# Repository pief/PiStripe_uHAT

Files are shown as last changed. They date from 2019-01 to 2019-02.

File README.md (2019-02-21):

# PiStripe uHAT

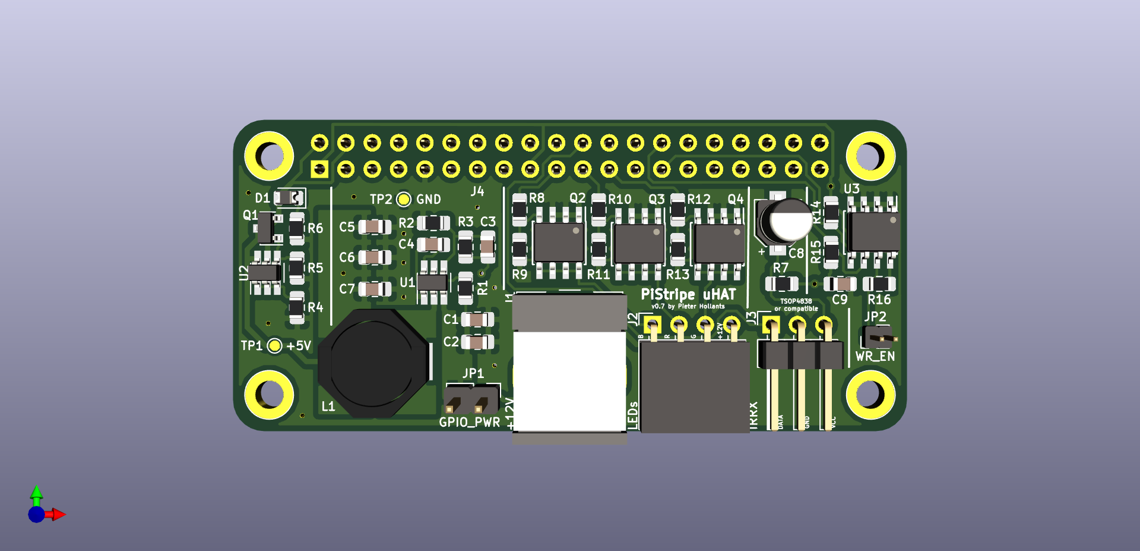
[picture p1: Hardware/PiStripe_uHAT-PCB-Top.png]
Image of PCB top side


## Background

Surely I'm not the only one having both a Raspberry Pi and an LED stripe flying around. In my case it was a "dumb", analogue 12V RGB LED stripe, meaning an LED strip without individually addressable LEDs - instead you generate different colors on the entire LED stripe by using pulse width modulation (PWM) on the R, G and B lines.

Interestingly, while there are plenty of tutorials on connecting such an LED stripe to the Raspberry Pi using transistors I wasn't able to find a ready-to-use HAT doing this. There are plenty of HATs driving LEDs directly mounted on the HAT (e.g. [Pimoroni's Ubercorn](https://shop.pimoroni.com/products/ubercorn) and [Unicorn](https://shop.pimoroni.com/products/unicorn-hat) HATs) and
there is [ManiacalLabs' PiPixel HAT](https://www.tindie.com/products/ManiacalLabs/pipixel-raspberry-pi-led-strip-hat/) but that one drives "digital" WS2812-based LED strips, not dumb ones such as mine. Knight of Pi simply [soldered the transistors on Adafruit's ProtoHAT](http://www.knight-of-pi.org/color-mixer-control-a-rgb-led-strip-with-the-raspberry-pi-and-the-n-channel-mosfet-irlb8721/)
but that seemed to me a bit too hackish for permanent use.

The closest existing solution is the [ANAVI Light pHAT](https://www.crowdsupply.com/anavi-technology/light-phat). It is designed for 12V RGB LED strips such as mine, however there were some points I didn't like. For instance, it uses a quite big screw terminal
where I'd prefer a more compact pin header that matches the existing LED strip connector. But most of all, I don't like having to use two power supplies, one with 12V for the LED strip and still one with 5V for the Raspberry Pi. Unfortunately, with the ANAVI pHAT, it was decided to not implement the back powering option, i.e. integrating a switching regulator to convert 12V to 5V and supply these to the Raspberry Pi via the GPIO pins. Instead the PCB space was used for various options for all kinds of sensors,
something I don't really need.

So I thought, inspite of being not literate at electronics enough I'd build something myself and take the best parts and features of existing solutions and combine them into a HAT of my own. After all, that's what open hardware is all about!

And with great success: the PiStripe uHAT has now been built and tested successfully!

## Features

The PiStripe uHAT is a board of the size of the Raspberry Pi Zero, thus a uHAT (not a HAT) as defined by the Raspberry Foundation. It can be attached on any Raspberry Pi with the 40 pin connector, not just the Pi Zero (W).

The uHAT features the following five functions:

- a 12V -> 5V buck converter based on Texas Instruments' [TPS54202](http://www.ti.com/lit/ds/symlink/tps54202.pdf) chip to implement "back powering" the Raspberry Pi via the GPIO pins, doing away with the need to use two power supplies (one 12V for the LED strip, one 5V for the Raspberry Pi).
- a "perfect" reverse current blocking diode schematic as described in the
  [Raspberry Foundation Add-On board / HAT design guide](https://github.com/raspberrypi/hats/blob/master/designguide.md) to prevent damage when accidentally connecting both 5V to the RPi via its MicroUSB connector and supplying power via my HAT does
  not cause damage.
- the actual LED strip driving
- the possibility to connect an external IR receiver such as a TSOP 34838 so you can use [LIRC](http://lirc.org/) to decode the signals sent by the LED strip's original remote control. External because the HAT is mounted on the Raspberry Pi which in turn will probably be hidden away in some corner whereas you will want to place the IR receiver at a place where it can actually "see" the remote control.
- an ID EEPROM so the board qualifies officially as a HAT as described in the [Raspberry Foundation Add-On board / HAT design guide](https://github.com/raspberrypi/hats/blob/master/designguide.md).

## Hardware

The PiStripe uHAT is not a ready-to-buy product. In fact it's not even a product as such. Instead, it's a do-it-yourself project. Consult the **Hardware** directory for the KiCad project files, including a parts list and the PCB ready for etching.

## Software

The PiStripe uHAT's ID EEPROM needs to be programmed once with the binary in the **Software/EEPROM** directory. The **Software** directory additionally contains some examples on how to use the PiStripe uHAT.

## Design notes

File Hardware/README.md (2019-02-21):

# PiStripe uHAT

## Hardware

The current v0.7 revision of the PiStripe uHAT has been successfully built and tested with the following remarks nonwithstanding:
- the pullups R9, R11 and R13 are probably unnecessary if the ID EEPROM is changed to use the Raspberry Pi's internal pull-up resistors.
- I used a bit of a too small font size, so if you can't read everything, it's not your eyes...

### GPIOs used

The PiStripe uHAT uses the following GPIO pins:

| GPIO pins | Pin name | Usage | Exclusive |
| :---: | :---: | :---: | :---: |
| 1, 17 | +3.3V | IR receiver, ID EEPROM | No |
| 2, 4 | +5V | Back powering Raspberry Pi | No |
| 6, 9, 14, 20, 25, 30, 34, 39 | GND | Ground | No |
| 19 | GPIO10_SPI_MOSI | LED color 1 (e.g. Red) | Yes |
| 21 | GPIO09_SPI_MISO |  LED color 2 (e.g. Green)  | Yes |
| 22 | GPIO25 | IR receiver data | Yes |
| 23 | GPIO11_SPI_CLK  | LED color 3 (e.g. Blue)  | Yes |
| 27 | ID_SD | ID EEPROM I2C Data | No |
| 28 | ID_SC | ID EEPROM I2C Clock | No |

### Jumpers

There are two jumpers:

| Jumper | Name | Function |
| :----: | :---: | :---: |
|  JP1 | GPIO_PWR | Open: Raspberry Pi is powered over Micro USB connector |
| | GPIO_PWR | Closed: Enable back powering the Raspberry Pi via GPIO |
|  JP2 | WR_EN  | Open: Normal usage |
| | WR_EN  | Closed: ID EEPROM can be programmed |

Whether you leave JP1 open or closed depends on whether you want to use the "back powering" feature, thus requiring only the LED stripe's +12V power supply, or keep supplying the Raspberry Pi via its Micro USB connector. Even if you accidentally close JP1 and still connect power to the Pi's Micro USB connector, nothing should go wrong thanks to the "perfect" reverse current blocking diode.

JP2 should only be closed once to program the ID EEPROM (no instructions and software for this yet) and stay open afterwards to prevent accidental flashing.

### Design files

The board's schematic and PCB have been designed with [KiCad](http://www.kicad-pcb.org), a really powerful Open Source EDA solution and a worthy alternative to commercial products such as Eagle.

#### Schematic

Here's an image of the schematic:

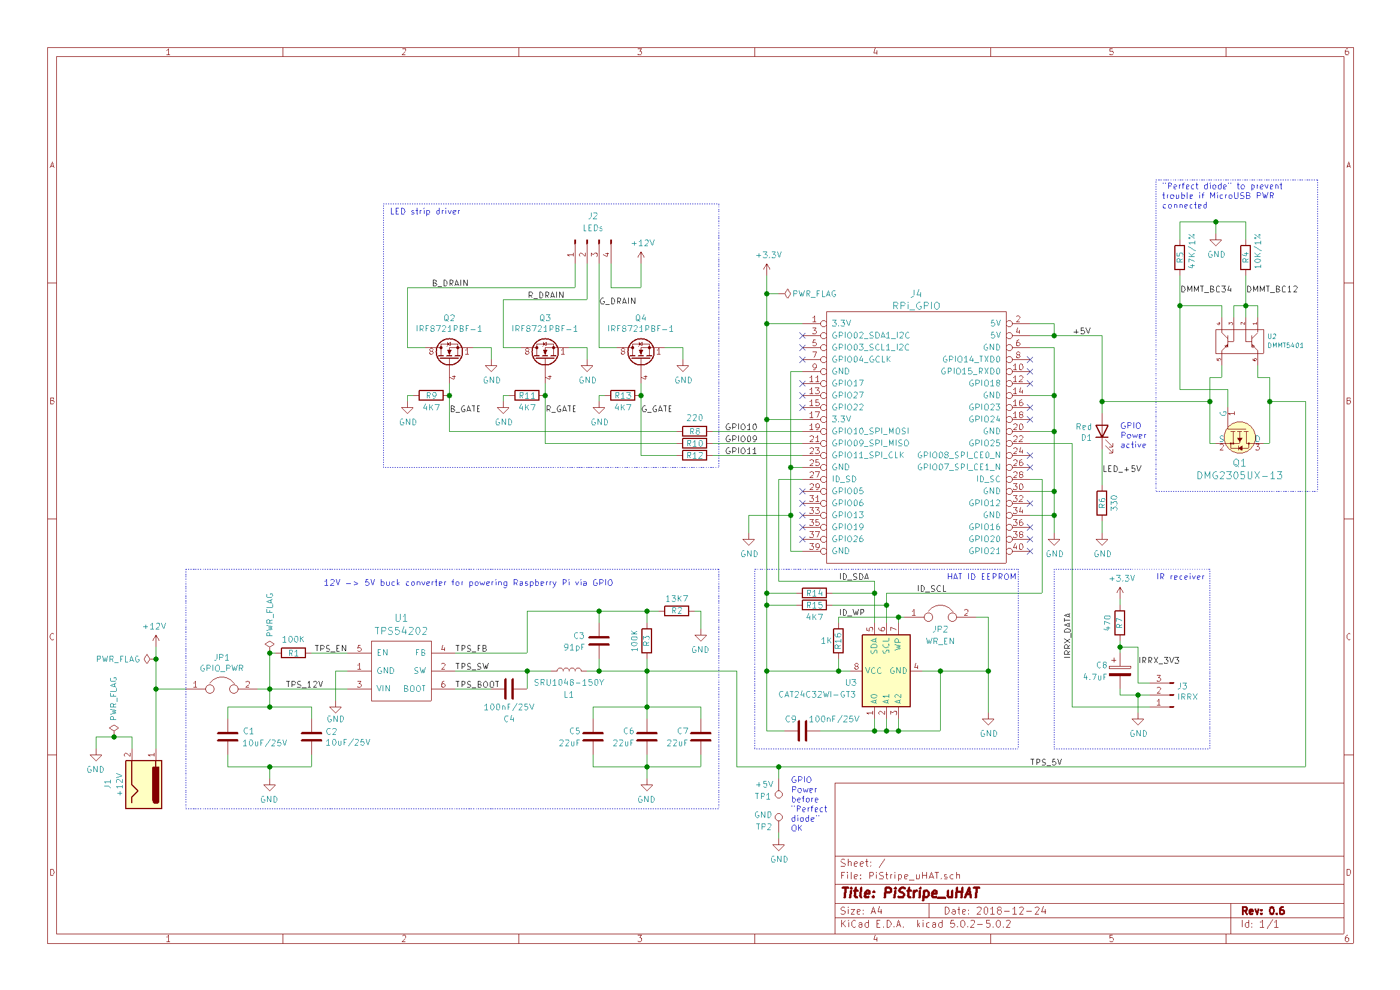
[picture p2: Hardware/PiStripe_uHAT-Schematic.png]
Image of Schematic


As you can see, the schematic is clearly divided into different blocks that corrospond to the functions listed above, so comparisons with the original sources for the schematics (see [Credits](#credits)) should be rather easy.

#### PCB

Here are some images of the PCB:

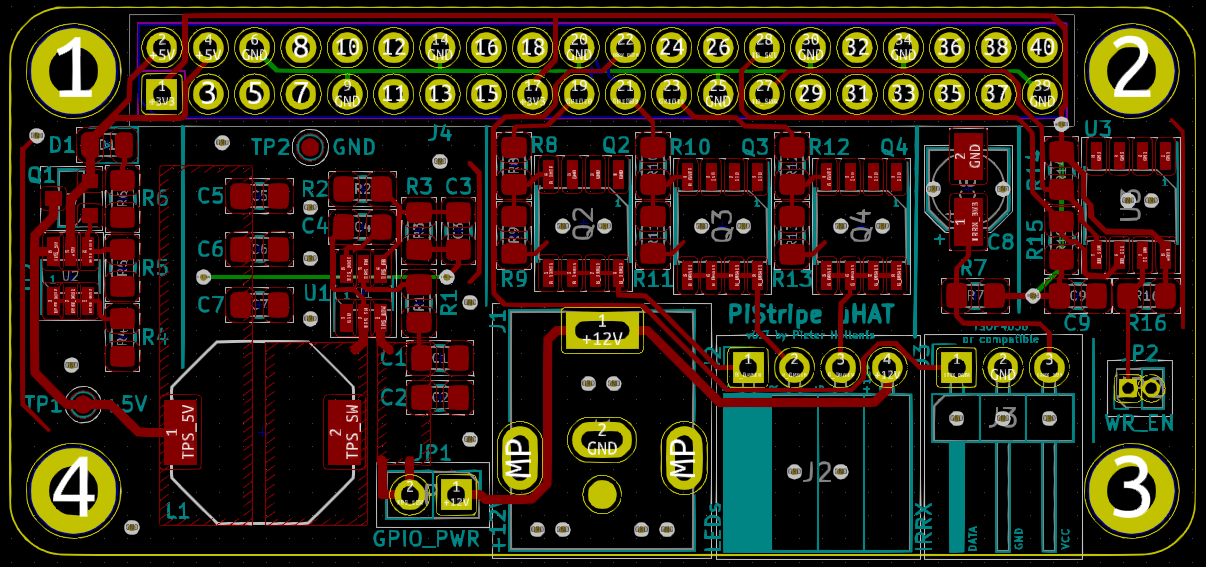
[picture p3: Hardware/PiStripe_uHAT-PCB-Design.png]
Image of naked PCB design

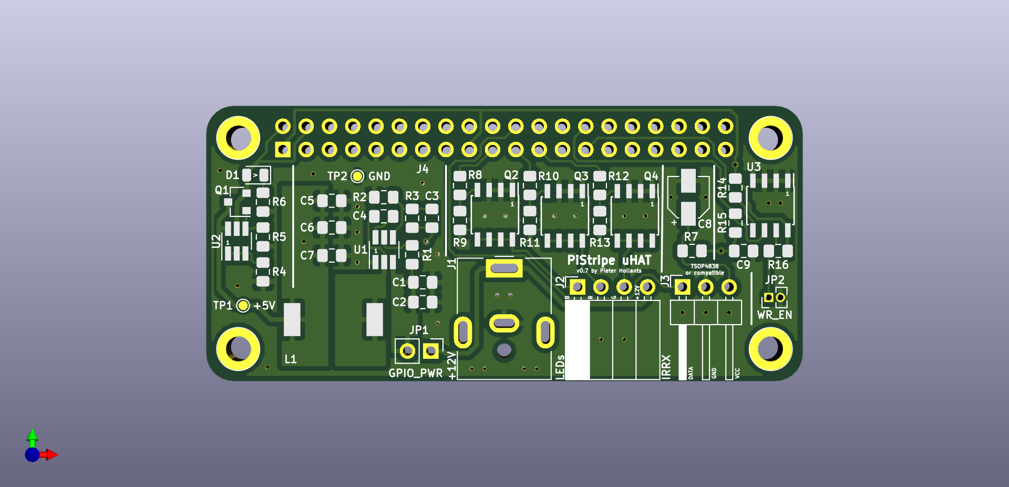
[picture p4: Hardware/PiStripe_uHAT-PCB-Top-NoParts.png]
Image of PCB top side without parts

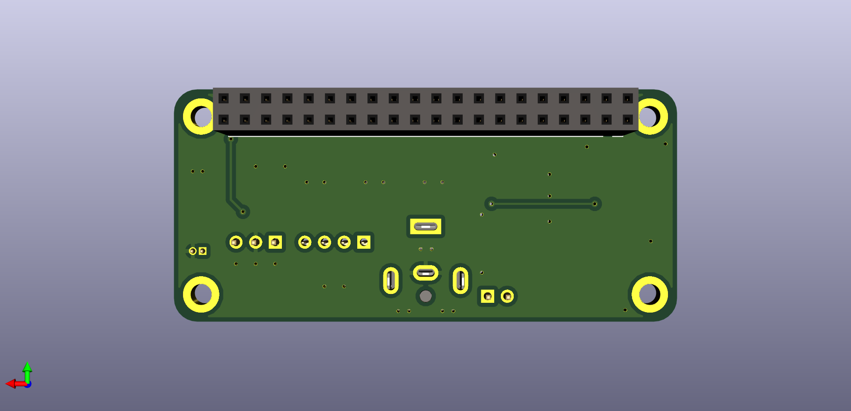
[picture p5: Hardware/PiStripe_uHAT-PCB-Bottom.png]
Image of PCB bottom side

Image of PCB top side

Like the schematic, the PCB has guiding lines printed on top to isolate the different function blocks.

#### Parts list

Please consult the [CSV part list](Hardware/PiStripe_uHAT_Parts.csv) for details.

### Credits

I'm not really inventing something new here but merely combining existing stuff into something new, so I'm standing on the shoulders of giants and try to give appropriate credits here. A big "Thank you" to the following people:

- **Alain Pannetrat** posted the Texas Instruments' [TPS54202](http://www.ti.com/lit/ds/symlink/tps54202.pdf)-based schematic and PCB for [Adding a DC power jack to the Raspberry Pi](https://www.omzlo.com/articles/adding-a-dc-power-jack-to-the-raspberry-pi-v2) on his omzlo.com blog. He did not explicitly specify a license, so I'll assume CC-BY-SA.
- **The Raspberry Foundation** published the circuit for the "perfect" reverse current blocking diode in their [Add-On board / HAT design guide](https://github.com/raspberrypi/hats/blob/master/designguide.md) (see the section "Back Powering the Pi via the GPIO Header" there and the [ZVD circuit schematic](https://github.com/raspberrypi/hats/blob/master/zvd-circuit.png).
- **Leon Anavi** published the schematic and PCB for his [ANAVI Light pHAT](https://www.crowdsupply.com/anavi-technology/light-phat) and his [ANAVI Infrared pHAT](https://www.crowdsupply.com/anavi-technology/infrared-phat) under the [CC-BY-SA 4.0](https://creativecommons.org/licenses/by-sa/4.0/) license. The LED driving circuit, the IR receiver circuit and the basic PCB design such as board dimensions, mounting holes etc. are based on his work. Note that for the IR receiver I use pin 22 (GPI25) instead of pin 12 (GPIO18) to be compatible with the [pHAT DAC](https://de.pinout.xyz/pinout/phat_dac).
- **Mike Lawrence** posted a [RPi_Zero_pHat_Template](https://github.com/mikelawrence/RPi_Zero_pHat_Template) from which I used symbols in ``Connector-ML.lib`` for the schematic. The template is licensed under the [MIT license](https://github.com/mikelawrence/RPi_Zero_pHat_Template/blob/master/LICENSE).
- **Digikey** provides a [KiCAD library](https://github.com/digikey/digikey-kicad-library) from which I used symbols in ``dk_Transistors-FETs-MOSFETs-Single.lib`` for the schematic. The library is licensed under the [CC-BY-SA 4.0](https://github.com/digikey/digikey-kicad-library/blob/master/LICENSE.md) license.
- **L. Bernstone** posted the schematic and design for a [3V3 DC/DC power supply layout using TPS54202](https://github.com/lbernstone/TPS54202/) from which I used symbols in ``tps54202.lib`` for the schematic.
- **Tinkerforge** provides [KiCAD libraries](https://github.com/Tinkerforge/kicad-libraries) from which I used symbols in ``DMMT5401.lib`` for the schematic. They are licensed under the [CERN Open Hardware License v1.1](https://github.com/Tinkerforge/kicad-libraries/blob/master/LICENSE.txt).
- **Philipp "Virtex7" Hörauf** provides a [Philipps Kicad Bauteile collection](https://github.com/Virtex7/PhilippsKicadBauteile/) from which I used the footprint ``SRU1048.kicad_mod`` in the PCB design. Since it didn't provide a 3D model, I modified it to use the one from the following paragraph. Philipp did not explicitly specify a license, so I'll assume CC-BY-SA.
- **ACSE & CADIEEL** provide [CIAA Hardware repository](https://github.com/ciaa/Hardware) from which I used the 3D model ``SRU1048.wrl`` together with the footprint in the previous paragraph. They use [their own license](https://github.com/ciaa/Hardware/blob/master/LICENSE).

### LICENSE

The PiStripe uHAT PCB and its design files are licensed [CC-BY-SA](LICENSE).

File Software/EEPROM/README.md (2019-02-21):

# PiStripe uHAT

## ID EEPROM

This directory contains the sources and the binary ready for flashing into the PiStripe uHAT's ID EEPROM.

### Rebuilding the binary

There is usually no need to rebuild the binary but if you want to do it anyway, install `dtc`, the Device Tree Compiler, and type `make`. This will automatically `git clone` the Raspberry Pi foundation's `hats` directory so we gain access to their `eepromutils`.

### Flashing the binary

After building the PiStripe uHAT, you need to flash the binary into the ID EEPROM to take advantage of
- HAT identification in `/proc/device-tree/hat/`
- accessing the LED outputs in `/sys/class/leds/`
- accessing IR receiver scancodes via `/dev/input/event*`

Flashing is done on the Raspberry Pi itself.

1. Power off the Pi.
2. Set the jumper on JP2 to enable writing to the EEPROM.
3. Power on the Pi.
4. `git clone` this repository on the Pi and `cd` to this directory.
5. Type `make flash`. This will automatically "git clone" the Raspberry Pi foundation's `hats` directory so we gain access to their `eepromutils`.
6. Power off the Pi.
7. Remove the jumper from JP2 to prevent accidentally writing to the EEPROM.
8. Power on the Pi and check `/proc/device-tree/hat/` to see if the ID EEPROM is being recognized correctly.

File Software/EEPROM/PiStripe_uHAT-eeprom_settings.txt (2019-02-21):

########################################################################
# EEPROM settings text file
#
# Edit this file for your particular board and run through eepmake tool,
# then use eepflash tool to write to attached HAT ID EEPROM 
#
# Tools available:
#  eepmake   Parses EEPROM text file and creates binary .eep file
#  eepdump   Dumps a binary .eep file as human readable text (for debug)
#  eepflash  Write or read .eep binary image to/from HAT EEPROM
#
########################################################################

########################################################################
# Vendor info

# 128 bit UUID. If left at zero eepmake tool will auto-generate
# RFC 4122 compliant UUID
product_uuid 3a4e28e5-7a0a-4101-b8fe-cf91223f8ad2

# 16 bit product id
product_id 0x0100

# 16 bit product version
product_ver 0x0007

# ASCII vendor string  (max 255 characters)
vendor "Pieter Hollants <pieter@hollants.com>"

# ASCII product string (max 255 characters)
product "PiStripe uHAT"

########################################################################
# GPIO bank settings, set to nonzero to change from the default.
# NOTE these setting can only be set per BANK, uncommenting any of
# these will force the bank to use the custom setting.

# drive strength, 0=default, 1-8=2,4,6,8,10,12,14,16mA, 9-15=reserved
gpio_drive 0

# 0=default, 1=slew rate limiting, 2=no slew limiting, 3=reserved
gpio_slew 0

# 0=default, 1=hysteresis disabled, 2=hysteresis enabled, 3=reserved
gpio_hysteresis 0

# If board back-powers Pi via 5V GPIO header pins:
# 0 = board does not back-power
# 1 = board back-powers and can supply the Pi with a minimum of 1.3A
# 2 = board back-powers and can supply the Pi with a minimum of 2A
# 3 = reserved
# If back_power=2 then USB high current mode will be automatically 
# enabled on the Pi
back_power 2

########################################################################
# GPIO pins, uncomment for GPIOs used on board
# Options for FUNCTION: INPUT, OUTPUT, ALT0-ALT5
# Options for PULL: DEFAULT, UP, DOWN, NONE
# NB GPIO0 and GPIO1 are reserved for ID EEPROM so cannot be set

#         GPIO  FUNCTION  PULL
#         ----  --------  ----
#setgpio  2     INPUT     DEFAULT
#setgpio  3     INPUT     DEFAULT
#setgpio  4     INPUT     DEFAULT
#setgpio  5     INPUT     DEFAULT
#setgpio  6     INPUT     DEFAULT
#setgpio  7     INPUT     DEFAULT
#setgpio  8     INPUT     DEFAULT
setgpio   9     OUTPUT    DEFAULT
setgpio   10    OUTPUT    DEFAULT
setgpio   11    OUTPUT    DEFAULT
#setgpio  12    INPUT     DEFAULT
#setgpio  13    INPUT     DEFAULT
#setgpio  14    INPUT     DEFAULT
#setgpio  15    INPUT     DEFAULT
#setgpio  16    INPUT     DEFAULT
#setgpio  17    INPUT     DEFAULT
#setgpio  18    INPUT     DEFAULT
#setgpio  19    INPUT     DEFAULT
#setgpio  20    INPUT     DEFAULT
#setgpio  21    INPUT     DEFAULT
#setgpio  22    INPUT     DEFAULT
#setgpio  23    INPUT     DEFAULT
#setgpio  24    INPUT     DEFAULT
setgpio   25    INPUT     DOWN
#setgpio  26    INPUT     DEFAULT
#setgpio  27    INPUT     DEFAULT

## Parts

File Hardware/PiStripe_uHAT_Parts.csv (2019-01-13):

Bezeichner | Gehäuse | Stückzahl | Bezeichnung | Mouser Part No
C1,C2 | C_0805_2012Metric_Pad1.15x1.40mm_HandSolder | 2 | 10uF/25V | 81-GRM21BC81E106KE5L
C3 | C_0805_2012Metric_Pad1.15x1.40mm_HandSolder | 1 | 91pF | 581-08055A910JAT2A
C4,C9 | C_0805_2012Metric_Pad1.15x1.40mm_HandSolder | 2 | 100nF/25V | 581-08053C104J
C5,C6,C7 | C_0805_2012Metric_Pad1.15x1.40mm_HandSolder | 3 | 22uF | 81-GRM21BD71A226ME4L
C8 | CP_Elec_4x5.8 | 1 | 4.7uF | 667-EEE-HC1V4R7R
D1 | D_0805_2012Metric | 1 | Red | 645-599-0110-007F
J1 | BarrelJack_CUI_PJ-063AH_Horizontal | 1 | +12V | 490-PJ-063AH
J2 | PinSocket_1x04_P2.54mm_Horizontal | 1 | LEDs | 437-8018700420001101
J3 | PinHeader_1x03_P2.54mm_Horizontal_Mirrored | 1 | IRRX | 200-HMTSW1037TS110RA
J4 | PinSocket_2x20_P2.54mm_Vertical | 1 | RPi_GPIO | 485-2223
JP1 | PinHeader_1x02_P2.54mm_Vertical | 1 | GPIO_PWR | 855-M7583-05 | 855-M20-9770242
JP2 | PinHeader_1x02_P1.27mm_Vertical | 1 | WR_EN | 855-M50-1920005 | 855-M50-3530242
L1 | SRU1048 | 1 | SRU1048-150Y | 652-SRU1048-150Y
Q1 | SOT-23 | 1 | DMG2305UX-13 | 621-DMG2305UX-7
Q2,Q3,Q4 | SOIC-8_3.9x4.9mm_P1.27mm | 3 | IRF8721PBF-1 | 942-IRF8721TRPBF
R1,R3 | R_0805_2012Metric_Pad1.15x1.40mm_HandSolder | 2 | 100K | 754-RR1220P-104D
R14,R15,R9,R11,R13 | R_0805_2012Metric_Pad1.15x1.40mm_HandSolder | 5 | 4K7 | 754-RR1220P-472D
R16 | R_0805_2012Metric_Pad1.15x1.40mm_HandSolder | 1 | 1K | 754-RR1220P-102D
R2 | R_0805_2012Metric_Pad1.15x1.40mm_HandSolder | 1 | 13K7 | 754-RR1220P-1372D-M
R4 | R_0805_2012Metric_Pad1.15x1.40mm_HandSolder | 1 | 10K/1% | 754-RR1220P-103D
R5 | R_0805_2012Metric_Pad1.15x1.40mm_HandSolder | 1 | 47K/1% | 754-RR1220P-473D
R6 | R_0805_2012Metric_Pad1.15x1.40mm_HandSolder | 1 | 330 | 754-RR1220P-331D
R7 | R_0805_2012Metric_Pad1.15x1.40mm_HandSolder | 1 | 470 | 754-RR1220P-471D
R8,R10,R12 | R_0805_2012Metric_Pad1.15x1.40mm_HandSolder | 3 | 220 | 754-RR1220P-221D
U1 | SOT-23-6_Handsoldering | 1 | TPS54202 | 595-TPS54202DDCR
U2 | SOT-23-6_Handsoldering | 1 | DMMT5401 | 621-DMMT5401-7-F
U3 | SOIC-8_3.9x4.9mm_P1.27mm | 1 | CAT24C32WI-GT3 | 698-CAT24C32WI-GT3

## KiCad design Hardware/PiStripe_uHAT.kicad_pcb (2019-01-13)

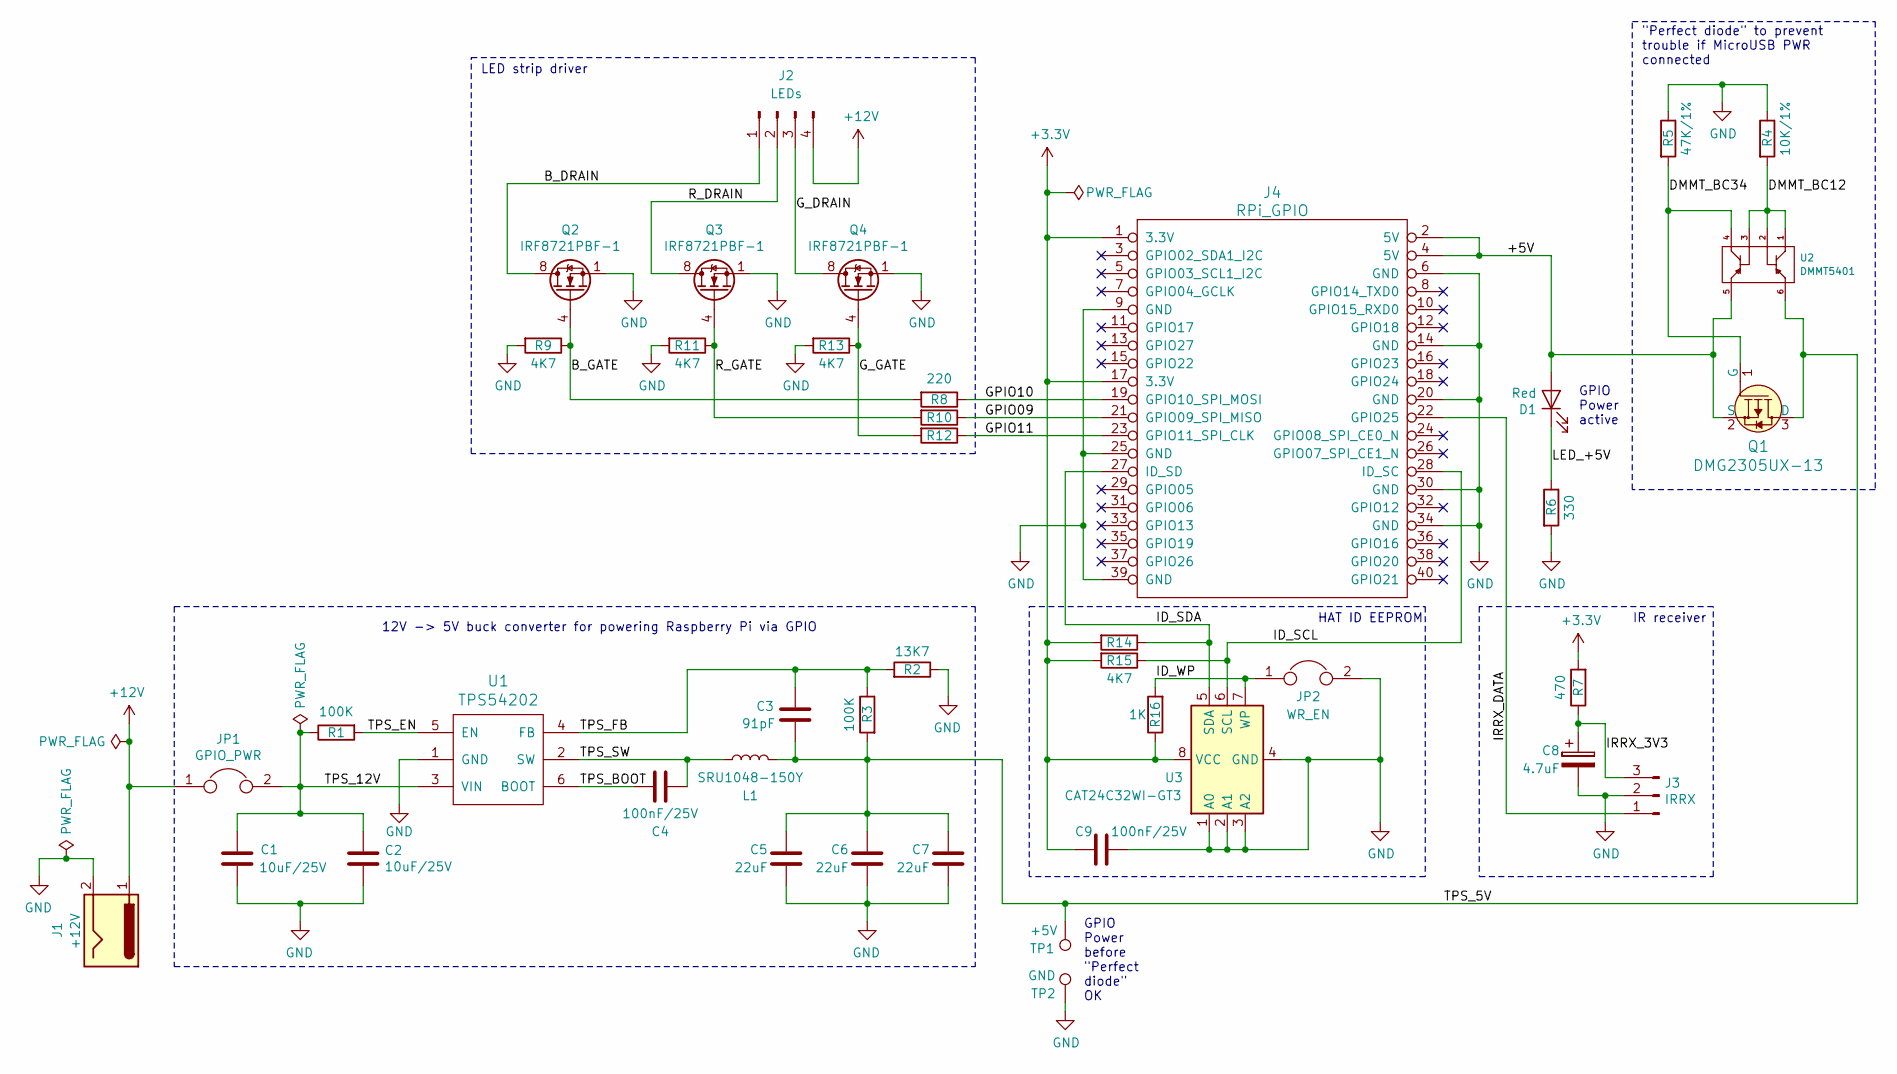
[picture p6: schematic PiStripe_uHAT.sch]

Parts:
C1, C2: 10uF/25V; C_0805_2012Metric_Pad1.15x1.40mm_HandSolder
C3: 91pF; C_0805_2012Metric_Pad1.15x1.40mm_HandSolder
C4, C9: 100nF/25V; C_0805_2012Metric_Pad1.15x1.40mm_HandSolder
C5, C6, C7: 22uF; C_0805_2012Metric_Pad1.15x1.40mm_HandSolder
C8: 4.7uF; CP_Elec_4x5.8
D1: Red; D_0805_2012Metric
J1: +12V; BarrelJack_CUI_PJ-063AH_Horizontal
J2: LEDs; PinSocket_1x04_P2.54mm_Horizontal
J3: IRRX; PinHeader_1x03_P2.54mm_Horizontal_Mirrored
J4: RPi_GPIO; PinSocket_2x20_P2.54mm_Vertical
JP1: GPIO_PWR; PinHeader_1x02_P2.54mm_Vertical
JP2: WR_EN; PinHeader_1x02_P1.27mm_Vertical
L1: SRU1048-150Y; SRU1048
Q1: DMG2305UX-13; SOT-23; MPN DMG2305UX-13; Digi-Key_PN DMG2305UX-13DICT-ND
Q2, Q3, Q4: IRF8721PBF-1; SOIC-8_3.9x4.9mm_P1.27mm
R1, R3: 100K; R_0805_2012Metric_Pad1.15x1.40mm_HandSolder
R2: 13K7; R_0805_2012Metric_Pad1.15x1.40mm_HandSolder
R4: 10K/1%; R_0805_2012Metric_Pad1.15x1.40mm_HandSolder
R5: 47K/1%; R_0805_2012Metric_Pad1.15x1.40mm_HandSolder
R6: 330; R_0805_2012Metric_Pad1.15x1.40mm_HandSolder
R7: 470; R_0805_2012Metric_Pad1.15x1.40mm_HandSolder
R8, R10, R12: 220; R_0805_2012Metric_Pad1.15x1.40mm_HandSolder
R9, R11, R13, R14, R15: 4K7; R_0805_2012Metric_Pad1.15x1.40mm_HandSolder
R16: 1K; R_0805_2012Metric_Pad1.15x1.40mm_HandSolder
TP1: +5V; TestPoint_Pad_D1.0mm
TP2: GND; TestPoint_Pad_D1.0mm
U1: TPS54202; SOT-23-6_Handsoldering
U2: DMMT5401; SOT-23-6_Handsoldering
U3: CAT24C32WI-GT3; SOIC-8_3.9x4.9mm_P1.27mm

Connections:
+3V3: C9.2, J4.1 (3.3V), J4.17 (3.3V), R7.2, R14.2, R15.2, R16.1, U3.8 (VCC)
+12V: J1.1, J2.4, JP1.1
/+5V: D1.2 (A), J4.2 (5V), J4.4 (5V), Q1.2 (S), U2.5
/B_DRAIN: J2.1, Q2.5 (D), Q2.6 (D), Q2.7 (D), Q2.8 (D)
/B_GATE: Q2.4 (G), R8.2, R9.1
/DMMT_BC12: R4.2, U2.1, U2.2, U2.3
/DMMT_BC34: Q1.1 (G), R5.2, U2.4
/GPIO09: J4.21 (GPIO09_SPI_MISO), R10.1
/GPIO10: J4.19 (GPIO10_SPI_MOSI), R8.1
/GPIO11: J4.23 (GPIO11_SPI_CLK), R12.1
/G_DRAIN: J2.3, Q4.5 (D), Q4.6 (D), Q4.7 (D), Q4.8 (D)
/G_GATE: Q4.4 (G), R12.2, R13.1
/ID_SCL: J4.28 (ID_SC), R15.1, U3.6 (SCL)
/ID_SDA: J4.27 (ID_SD), R14.1, U3.5 (SDA)
/ID_WP: JP2.1, R16.2, U3.7 (WP)
/IRRX_3V3: C8.1, J3.3, R7.1
/IRRX_DATA: J3.1, J4.22 (GPIO25)
/LED_+5V: D1.1 (K), R6.1
/R_DRAIN: J2.2, Q3.5 (D), Q3.6 (D), Q3.7 (D), Q3.8 (D)
/R_GATE: Q3.4 (G), R10.2, R11.1
/TPS_5V: C3.2, C5.1, C6.1, C7.1, L1.1, Q1.3 (D), R3.2, TP1.1, U2.6
/TPS_12V: C1.1, C2.1, JP1.2, R1.1, U1.3 (VIN)
/TPS_BOOT: C4.1, U1.6 (BOOT)
/TPS_EN: R1.2, U1.5 (EN)
/TPS_FB: C3.1, R2.2, R3.1, U1.4 (FB)
/TPS_SW: C4.2, L1.2, U1.2 (SW)
GND: C1.2, C2.2, C5.2, C6.2, C7.2, C8.2, C9.1, J1.2, J3.2, J4.6 (GND), J4.9 (GND), J4.14 (GND), J4.20 (GND), J4.25 (GND), J4.30 (GND), J4.34 (GND), J4.39 (GND), JP2.2, Q2.1 (S), Q2.2 (S), Q2.3 (S), Q3.1 (S), Q3.2 (S), Q3.3 (S), Q4.1 (S), Q4.2 (S), Q4.3 (S), R2.1, R4.1, R5.1, R6.2, R9.2, R11.2, R13.2, TP2.1, U1.1 (GND), U3.1 (A0), U3.2 (A1), U3.3 (A2), U3.4 (GND)

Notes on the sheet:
"Perfect diode" to prevent trouble if MicroUSB PWR connected
12V -> 5V buck converter for powering Raspberry Pi via GPIO
LED strip driver
IR receiver
HAT ID EEPROM
GPIO Power active
GPIO Power before "Perfect diode" OK

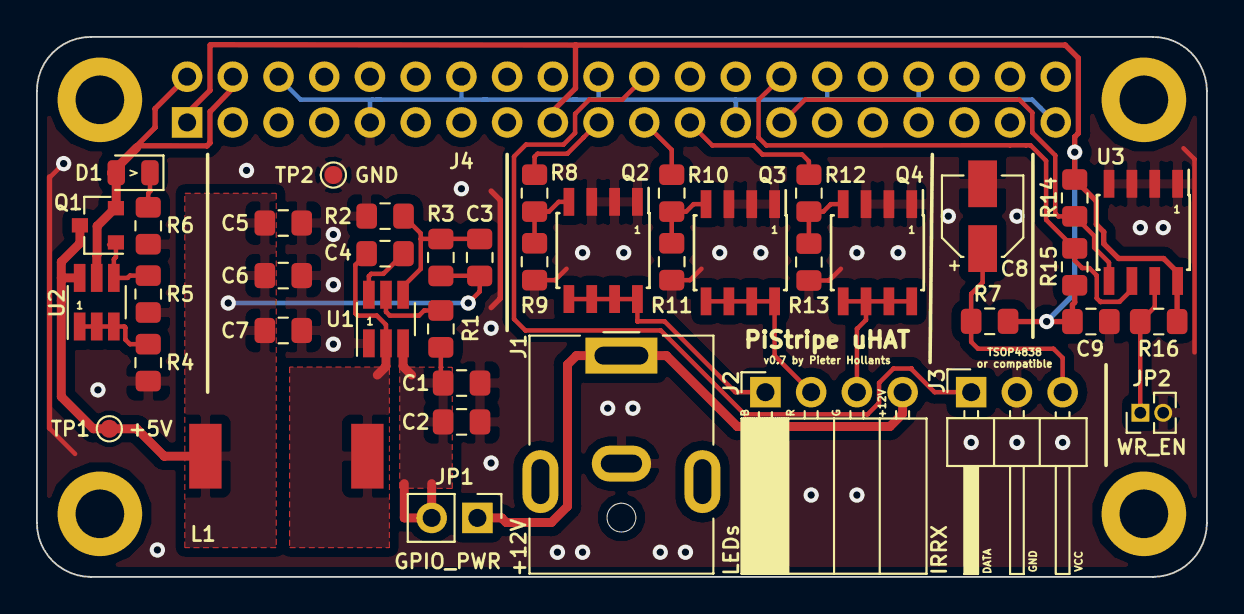
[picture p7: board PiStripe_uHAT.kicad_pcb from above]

Board: 2 copper layers, 65.0 x 30.0 mm, 46 parts (1 on the bottom side), 27 nets.

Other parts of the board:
REF1, REF2, REF3, REF4: MountingHole_2.7mm_M2.5_DIN965_Pad

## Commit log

2018-12-21 Add images of schematic and PCB
2018-12-21 PCB: Add one more guide line, move C5-C7 a bit
    [PiStripe_uHAT.kicad_pcb]
2018-12-23 v0.2: Small purely cosmetical update to the PCB
    [PiStripe_uHAT.kicad_pcb]
2018-12-23 v0.3: Additional Vias on GND plane near TPS54202, C9 routing optimized
    [PiStripe_uHAT.kicad_pcb]
2018-12-23 v0.4: Change GPIO for IRRX from Pin 12 (GPIO18) to 22 (GPIO25)
    Pin 12/GPIO18 is used by the phatDAC HAT which I want to combine with my
    PiStripe uHAT.
    [PiStripe_uHAT.kicad_pcb, PiStripe_uHAT.sch]
2018-12-23 README.md: Update IRRX pin for v0.4
2018-12-24 Turn GND arrows down in schematic
    [PiStripe_uHAT.sch]
2018-12-25 Add LIRC configuration file for and photo of my LED stripe remote
2018-12-25 Schematic: Tidy up IR receiver section
    [PiStripe_uHAT.sch]
2018-12-25 Board v0.5: Tidy right half of PCB
    - Move Q2/Q3/Q4 more to the left
    - Use generated space to move U3, R11, R12, R13 and C9 up right, placing
    JP2 below U3, making it visually easier to find
    - Move C8 next to R10, above J3
    - Connect to J1 separately from both sides to ensure better voltage flow
    - Add pin description labels to J2 and J3 (note J2 R/G/B assignment may
    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
    [PiStripe_uHAT.kicad_pcb]
2018-12-26 Clean up PCB wires
    [PiStripe_uHAT.kicad_pcb]
2018-12-26 Updated parts list
    [PiStripe_uHAT_Parts.csv]
2018-12-26 Schematic: Correct label text orientation
    [PiStripe_uHAT.sch]
2018-12-26 Use 25V instead of 50V for C1, C2, C4
    Should be totally sufficient and is available in 0805 form factor.
    [PiStripe_uHAT.sch, PiStripe_uHAT_Parts.csv]
2019-01-02 v0.6: Pulldowns for GPIO 09-11, reroute IRRX DATA, correct footprints etc.
    - Added pulldown resistors on GPIO 09-11, the gate lines of the IRF8721PBFs
    to ensure an undefined state at powerup doesn't cause the MOSFETs to
    operate and make the LEDs flicker.
    - Named nets in schematic for easier tracing in the PCB design.
    - Rerouted IRRX DATA line on top side to avoid long GND-dividing trace on
    bottom side.
    - Corrected parts and footprints for JP1 and JP2 to 2,54mm instead of
    1,27mm since these are supposed to be opened or closed via jumpers.
    - Corrected part and footprint for J4 to a pin socket instead of a pin
    header since the PCB is supposed to be stacked on top of the Raspberry
    Pi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
    [PiStripe_uHAT.kicad_pcb, PiStripe_uHAT.sch, PiStripe_uHAT_Parts.csv]
2019-01-13 v0.7: Correct connections and footprints for J2 and J3
    - Corrected J2 connections from R/G/B/+12V to B/R/G/+12V layout
    because that's what most LED strips actually use connector-wise.
    - Flipped J3 connections, Pin 1/DATA is now left, so that you can
    solder in a TSOP4838 directly if you want to.
    - Corrected footprints for J2 and J3 to 2.54mm pitch.
    - This required moving J1 and the entire voltage regulator
    section a bit to the left, rotating U3 and rearranging related
    parts as well as moving R7 and C8 for the TSOP.
    - Changed JP2 to 1.27mm pitch again because there are actually
    1.27mm jumpers available, the space was needed and this jumper is
    less likely to be changed than JP1.
    - R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
    [PiStripe_uHAT.kicad_pcb, PiStripe_uHAT.sch, PiStripe_uHAT_Parts.csv]
